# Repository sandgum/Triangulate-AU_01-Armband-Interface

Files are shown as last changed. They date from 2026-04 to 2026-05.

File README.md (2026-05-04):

# Triangulate-AU_01-Armband-Interface

## Description

A sci-fi-style armband interface running Android 14 on a Rockchip RK3576 module in a custom carrier board. Features an 8-inch 2.8K curved AMOLED with touch capabilities, a 2.1-channel speaker system with a 20W subwoofer, a 1080p pop-up webcam, various sensors, a huge battery at approx. 80Wh and 65W USB-PD charging. Perfect for use in the field with its bright display and long battery life.

## Enclosure

### Features
* 185mm long, with a radius of 56mm in the display section
* Four battery compartments housing 16x 1200mAh batteries with integrated cable channels
* Upwards-facing speaker channels for mid-high frequency drivers
* Integrated sealed subwoofer chamber
* Slim 38mm wide compute board in a hinged section
* Contoured inner profile (in contact with arm)
* Pop-up laptop webcam

### Images
au01 image 1
au01 image 3
au01 image 2

## Electronics

### Features
* PCIe x1 slot for NVMe SSD
* HDMI 2.1 port for display
* Two USB-C ports
* Port 1: USB-2.0, USB-PD-3.1 sink (Max. 20V) (for battery charging)
* Port 2: USB-3.0 SuperSpeed, USB-2.0, 5V 3A BC1.2 source (for peripherals)
* Approx. 60W battery charging via BQ25798
* Audio digital signal processing via ADAU1701
* 20W PAM8320 amplifier (for subwoofer)
* 2x 2W PAM8302 amplifiers (for L/R channels)

### PCB Schematics

Screenshot 2026-04-28 at 11 33 23 am

*Main RK3576 Module, HDMI, and PCIe*

Screenshot 2026-04-28 at 11 33 39 am

*USB-C Ports*

Screenshot 2026-04-28 at 11 33 50 am

*Battery Charger Circuit*

Screenshot 2026-05-04 at 12 30 20 pm

*Audio System Circuit*

### PCB Layout (Coming Soon!)

### Bill Of Materials (Coming Soon!)

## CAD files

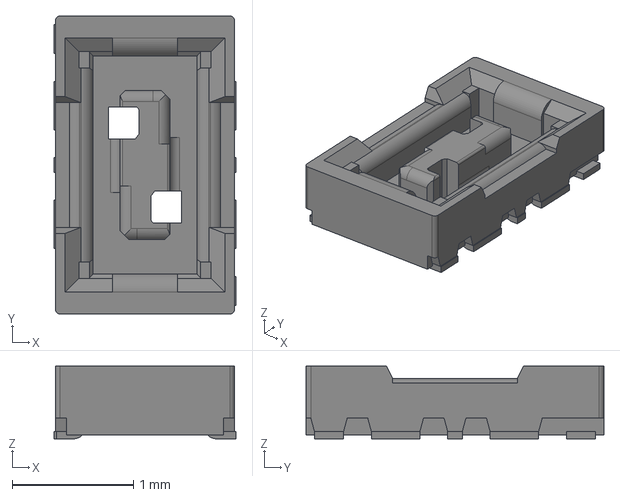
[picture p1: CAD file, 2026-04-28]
PCB/Additional Components/BM29B0.6-2DS_2-0.35V_51_/BM29B0.6-2DS_2-0.35V_51_.step
1.50 x 2.46 x 0.6 mm

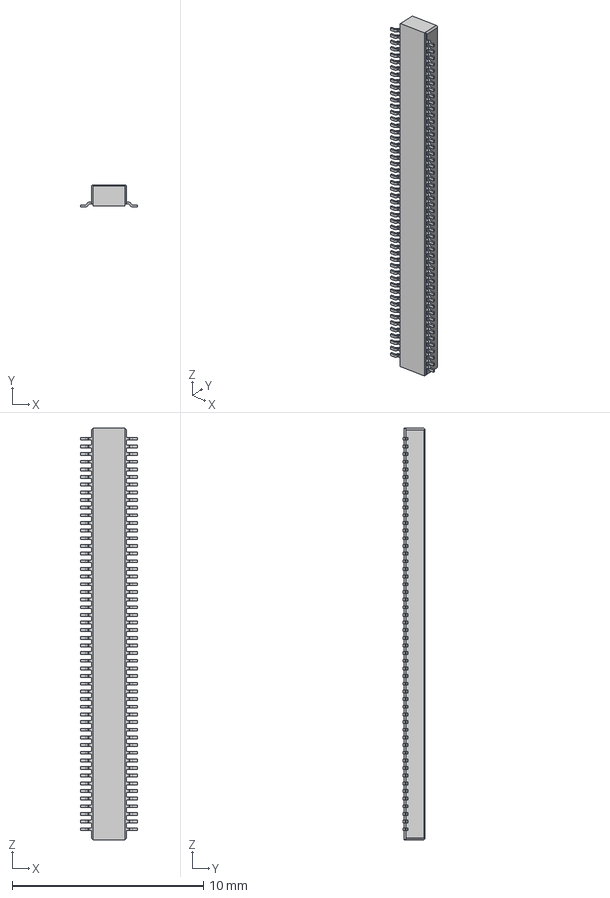
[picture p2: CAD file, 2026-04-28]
PCB/Additional Components/DF40C-100DP 0.4V Model/DF40C-100DP-0.4V_51_.step
2.97 x 1.14 x 21.5 mm

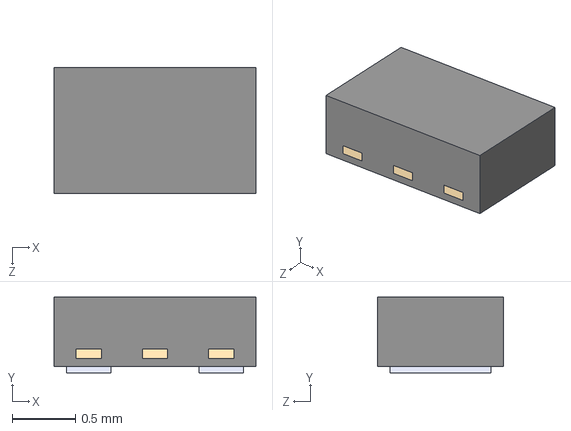
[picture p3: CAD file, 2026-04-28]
PCB/Additional Components/ESDA25P35 3D Model/ESDA25P35-1U1M.step
1.60 x 0.6 x 1.00 mm

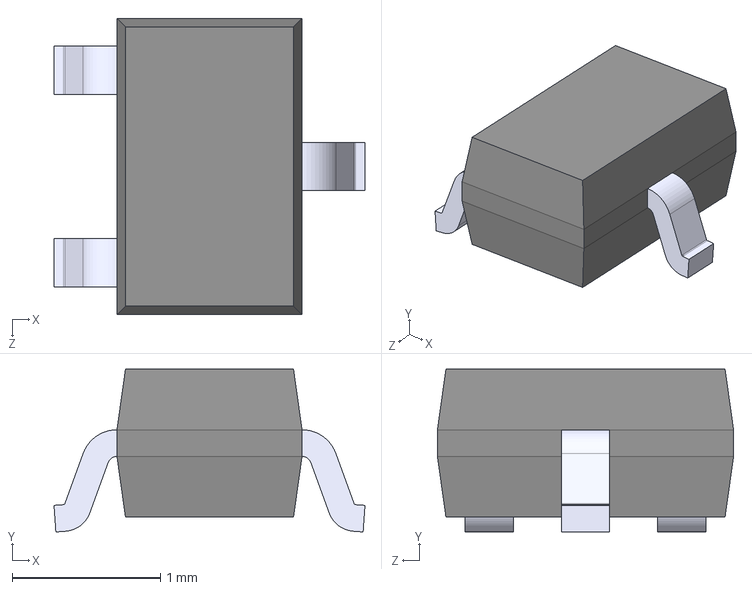
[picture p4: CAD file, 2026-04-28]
PCB/Additional Components/ESDA25W Model by STMicroelectronics/ESDA25W.step
2.10 x 1.10 x 2.00 mm

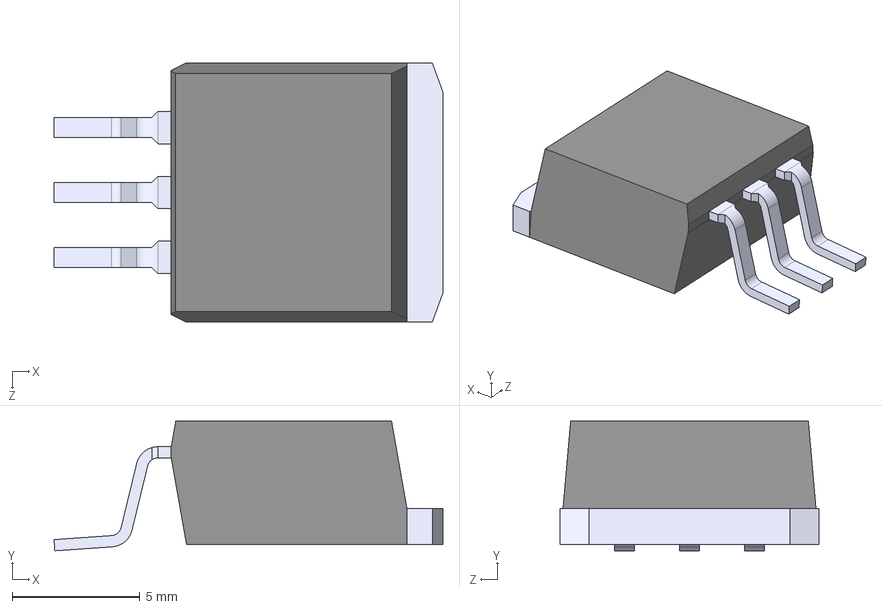
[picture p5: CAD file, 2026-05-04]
PCB/Additional Components/LM1085IS-12 Model/LM1085IS-12.step
15.2 x 5.08 x 10.2 mm

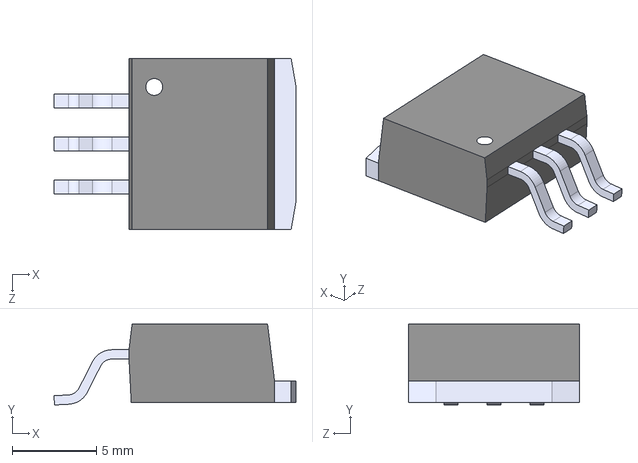
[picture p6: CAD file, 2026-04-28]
PCB/Additional Components/LM1085ISX-5.0_NOPB/LM1085ISX-5.0_NOPB.step
14.4 x 4.80 x 10.2 mm

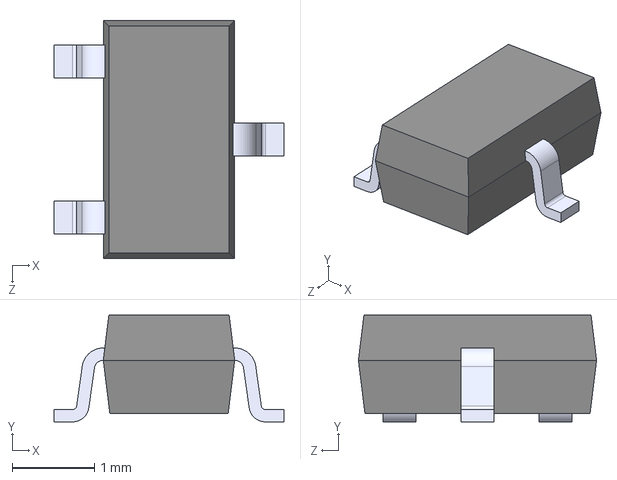
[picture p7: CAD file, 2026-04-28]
PCB/Additional Components/PMIC-LDO-XC6206P332MR-G_SOT23_/PMIC-LDO-XC6206P332MR-G_SOT23_.step
2.80 x 1.30 x 2.90 mm

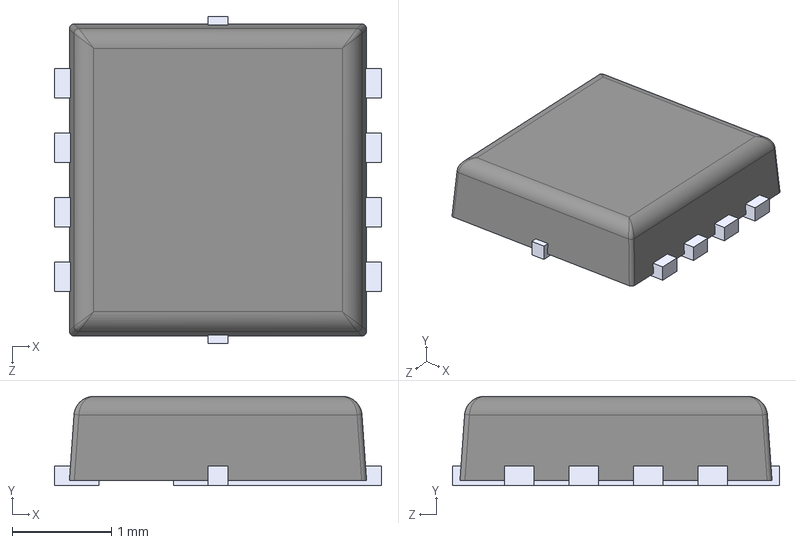
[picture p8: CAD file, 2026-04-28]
PCB/Additional Components/STL6P3LLH6 Model/STL6P3LLH6.step
3.30 x 0.9 x 3.30 mm

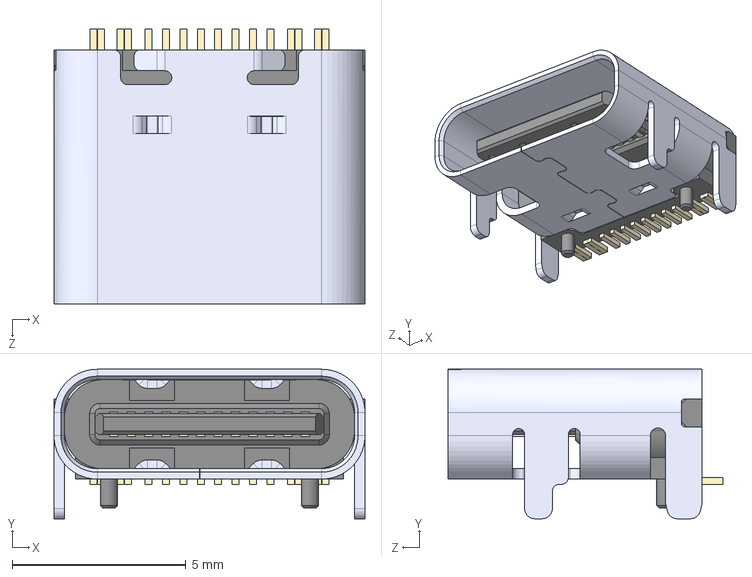
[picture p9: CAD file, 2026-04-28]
PCB/Additional Components/Type C 31 M 12 3D Model STEP 56544.STEP
8.94 x 4.30 x 7.90 mm

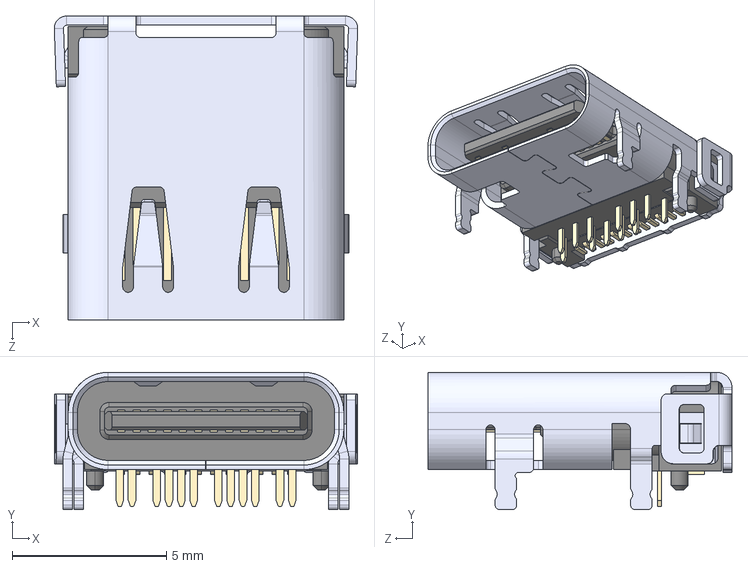
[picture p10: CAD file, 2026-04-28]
PCB/Additional Components/TYPE-C-31-M-04/TYPE-C-31-M-04.step
9.85 x 4.46 x 9.87 mm

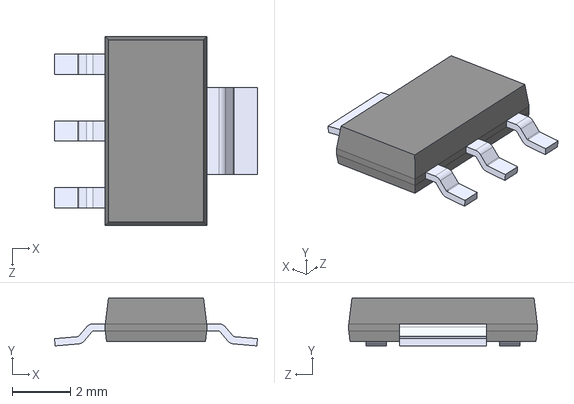
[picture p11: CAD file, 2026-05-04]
PCB/Additional Components/ZX5T953GTA Model/ZX5T953GTA.step
7.00 x 1.65 x 6.50 mm

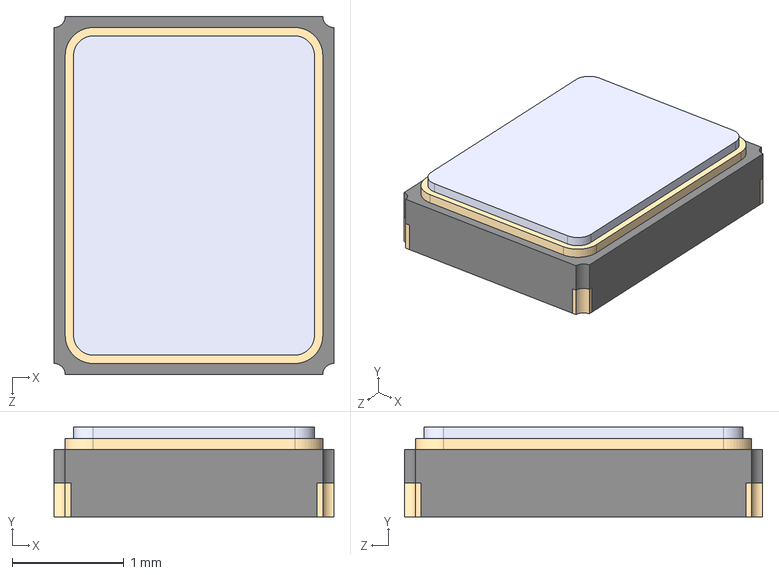
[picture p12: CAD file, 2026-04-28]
PCB/Additional Components/X322516MLB4SI/X322516MLB4SI.step
2.50 x 0.8 x 3.20 mm

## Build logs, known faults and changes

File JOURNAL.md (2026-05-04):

<!--
  This journal is auto generated by Stasis.
-->

# 5/4/2026 2 AM - Created Battery, Audio System Schematics

_Time spent: 5.75h_

After implementing the all-important USB-C ports, it was time to focus my attention towards the lesser, but still hugely important parts of the AU_01. 

To start, I researched various different multi-cell li-ion battery chargers. Initially, I wanted to use a BQ25730 IC from TI for its very fast maximum charging speed, but found that its application schematic required four external MOSFETs, without any recommendation for what model or parameters to even look for. I started researching suitable MOSFETs for this chip, but eventually I found that the schematic would take up too much space on the board, so I abandoned the idea of using that IC.

Screenshot 2026-05-04 at 12.06.23 pm

I then started reasearching again, finding a bunch of interesting options from TI again. Most notably, I found a much more integrated IC, the BQ25798, that incorporated all its MOSFETs into its package, saving me both valuable board space and also the headache and uncertainty of selecting my own MOSFETs for the charger. This did come with a tradeoff of only allowing around 60W of maximum charging power into my 4S pack. For an 80Wh system, that means it would take a minimum of around 1h 20m to charge the battery from 0 to 100%. It isn't as fast as I hoped to get it, but again, this thing has more battery capacity than my laptop and sips around the same or less power.

Screenshot 2026-05-04 at 12.07.08 pm

So there was my battery charger choice confimed, so I implemented the application schematic for it on a separate sheet, and that's when I ran into a problem. The BQ25798 requires some configuration and real-time management through I2C, which is easy enough to implement in my SoM, but that's where the problem lies. If I were to link the I2C up to my SoM, it would require the full system to be on just for the battery to charge, which would be a huge oversight that would affect usability. So for this application, I opted to use a tiny MAX32660 MCU (the same model used in the MS_01 studs!) because of its ridiculous power efficiency, tiny size and minimal external component count. After all, I only need this thing to write a couple of I2C registers and manage basic state.

Screenshot 2026-05-04 at 12.07.46 pm

Next, it was time to move on to designing the audio system circuitry. I want the AU_01 to have an integrated DSP and three amplifiers, one for each speaker driver. For the DSP, I used the easiest-to-program and most integrated option available, which is the ADAU1701 by Analog Devices. This DSP chip integrates DACs and ADCs, as well as internal logic circuitry and can be programmed easily using the SigmaStudio GUI. 

Screenshot 2026-05-04 at 12.09.55 pm

I chose the PAM8320 amplifier chip for the subwoofer, as it requires a minimal number of external components and is a well-known amplifier IC that can reliably deliver 20W for the Tectonic Elements driver. For the Dayton Audio stereo speaker, which only require 2W each, I used the PAM8302 amplifier chips for the same reasons as the larger amplifier, and I implemented the application schematics for all three chips. Conveniently, the PAM8302 ICs run perfectly on 5V, and the PAM8320 is fine with a 12V input. So the 5V supply for the smaller speakers can be shared with the SoM, and the 12V supply (after replacing the 1A regulator with a beefy 3A one) of the larger speaker can be shared with the OLED display, as its driver board takes a 12V input.

Screenshot 2026-05-04 at 12.10.25 pm

I then implemented the application schematic for the ADAU1701, and wired it so that it takes an I2S input and outputs three different analog signals, one for each
amplifier. 

Screenshot 2026-05-04 at 12.10.59 pm

During this, I ran into a problem, where the ADAU1701 specified using a 12.288MHz oscillator to generate a clock signal on its MCLK pin. This pin is also used by I2S, where the SoM provides its own MCLK for the chip to function at. Since MCLK can be driven at multiple clock frequencies (based on the sampling rate of the audio being played), I thought that foregoing the external oscillator and using the SoM's clock was a good choice. I also chose to do this because any mismatch in the MCLK between the chip's oscillator and the SoM's clock would result in the signal from the SoM (which depends on ITS clock) being jumbled up.

However, I realised that the ADAU1701 would require an instant clock signal upon power-on, and the SoM would definitely have some delay in turning on its MCLK. Also, since I'm using Android, it automatically limits its sampling rate to 48kHz, which results in a perfect 12.288MHz clock everytime. Therefore, I kept the external oscillator and left the SoM's MCLK signal unconnected. 

Now, the schematic for the entire AU_01 was pretty much done, and the only thing I needed to do was to add some sensors and supporting circuitry for a USB webcam.








# 4/28/2026 1 AM - Created USB-C Schematics

_Time spent: 5h_

Sooooo, I had to start actually creating the schematic diagrams for the various functions I want the AU_01 to support, and the most important (and probebly the hardest) one that I want to tackle are the USB-C ports that make up the primary method of interfacing with the device, and also the primary charging method.

I decided that I will include two USB-C ports on the device: One for USB-PD charging and USB2.0 data transmission for basic data transfer. For this, I used the STUSB4531 from ST, as it is a modern PD controller capable of running completely autonomously and is powered by the VBUS, so it can even charge completely dead batteries. Furthermore, the PD controller integrates a gate driver for a MOSFET for switching VBUS on and off, while also being able to negotiate contracts of more than 100W.

Screenshot 2026-04-28 at 11.13.08 am

The chip, however, only supports being a USB-PD sink, so it can only negotiate contracts where it takes power from an external source. This is why this port isn't good for unpowered peripherals (like keyboard/mouse dongles), as they simply won't receive any power. Additionally, the STUSB4531 hogs the CC pins on the USB-C port for itself, and it doesn't support USB-3.0 muxing across the port, so it will also be limited to USB-2.0 speeds. Considering the newest iPhones have that speed across their only USB-C port (yikes), I think the AU_01 having a full-speed USB-3.0 port in addition to the charging port is perfectly fine.

Screenshot 2026-04-28 at 11.16.03 am

Following the application schematic for the STUSB4531, and ddding the same high-speed low-capacitance ESD protector chips as I used in the HDMI port to the USB-2.0 data lines, the electrical design for the charging USB-C port was done. It can negotiate PD contracts up to 100W at 20V, which is perfect to charge the AU_01's battery in a reasonable time. Of course, there is a little bit of programming that needs to be done to the PD controller IC, but that only involves changing a few values in its NVM using an STM32 Nucleo board. That's why I've added a pin header for the chip's programming as well.

Next up was the design of the full-speed USB-3.0 port that also needs to provide power as a source to any peripherals or small dongles. This needed a set of different chips, which includes the FUSB302 Type-C controller and the TPS2547 power controller. The FUSB302 handles the CC pins and determines the USB-C plug's orientation. This then sends a signal to the I-CORE3576Q38 via I2C to let it know which orientation the port is in, which then results in the system module multiplexing its USB-3.0 signal to connect to the device.

In normal USB-3.0 outputs from a module, the signal multiplexing would be handled externally on the carrier board, but curiously the module I'm using has a multiplexer already inside. I used the FUSB302 to make sure that Linux recognises the device and lets the USB signal be routed to the correct pins.

To make sure any peripherals have adequate power supplied by the AU_01, I used the TPS2547 from Texas Instruments, which monitors the VBUS and negotiates power contracts up to 15W not using the CC pins, but the USB-2.0 data lines in an older protocol called BC1.2.

Screenshot 2026-04-28 at 11.17.16 am

Screenshot 2026-04-28 at 11.17.47 am

Connecting everything up to the system on module, I finally finished the implementation of USB-C on the AU_01. Next, I have to implement battery charging and other components like PCIe and MIPI-CSI for a camera.






# 4/10/2026 4 PM - Started PCB Design

_Time spent: 3.25h_

I finally started the main compute board design for the AU_01. Putting the main compute module on the schematic, I started working on the most important component of the board, which is the HDMI connector.

After finding a suitable connector that is cheap and in stock on LCSC, I routed the HDMI signals from the module to the connector. To add some ESD protection (because the RK3576 module is the most expensive part of the project), I placed a couple of ultra-low-capacitance ESD arrays designed for fast HDMI TMDS signals in the path of the lines. I placed another smaller ESD array for the I2C and Hot Plug Detect signals that are nowhere near as fast as the main TMDS signals, so the capacitance could be higher. Finally, I placed a high-power ESD diode for the 5V HDMI power rail, as well as a couple of decoupling capacitors for power stability.

Screenshot 2026-04-10 at 9.29.54 pm

The next part of the PCB I need to figure out is the whole charging circuit that uses USB PD through a Type-C port. This will require a PD controller IC, which range a lot in complexity and external component count. A cheap and easy option is to use the IP2366 IC, which integrates PD negotiation and battery charging all in one chip, but has sketchy documentation and is only available on AliExpress and AliBaba. Instead of this, I decided to go with a separate PD controller and charger combo from well-known brands.

I don't want to program any firmware for the controller (because that requires expensive programmers and introduces more points where my stupidity can cause failure), so the STUSB4531 by ST is a very good choice for my application. I then decided to pair that PD controller with a BQ25730 charging IC by TI, which can push up to 16.2A into my 4S pack.

Screenshot 2026-04-10 at 9.30.40 pm
Screenshot 2026-04-10 at 9.31.20 pm

To balance 4 series cells, it would have been too complicated (and dangerous) to prototype my own balancing circuit, so I decided to use an off-the-shelf module from AliExpress.

Next, I have to wire up these two ICs and complete the whole PD circuit!





# 4/9/2026 4 PM - Created I-CORE3576Q38 Footprint and Symbol

_Time spent: 2.5h_

This genuinely took a crazy amount of time. 

I went to start designing the PCB schematic, only to find that I couldn't find ANY footprint or symbol for the Firefly I-CORE3576Q38 anywhere. I had to message the manufacturer on WhatsApp to even get a 3D model and mechanical drawing, and I traced the connector model to the DF40HC(3.0)-100DS-0.4V(51) and DF40C-100DP-0.4V(51) by Hirose.

Screenshot 2026-04-09 at 10.10.22 pm

After getting the footprint and symbols for those two connectors, I merged them together to make a symbol, where I had to manually copy and paste all the pin names and pin numbers from the module's datasheet. This was by far the most time consuming part, as there are 200 pins to name on the module.

Screenshot 2026-04-09 at 10.08.49 pm

The PCB footprint was equally tedious, as I had to re-number every pin on one of the connectors to make it match with the symbol. I also used the 3D model of the module for reference to precisely place each connector so that it would line up with the expected boundaries of the module, and more importantly, line up relative to each other. Taking care to note which side of the module pin 1 on either connector was facing, I finally finished the footprint for this module (in true April fasion, complete with a couple of silkscreen Easter eggs!).

Screenshot 2026-04-09 at 10.09.39 pm





# 4/7/2026 4 PM - Modelled compute unit section, enclosure done!

_Time spent: 2.5h_

I had finally finished almost all of the enclosure for the AU_01, and the only thing left to model was the section that houses the main compute board. This board will be a carrier board for the RK3576 module, have HDMI and USB for connection to the display, have a Li-ion battery charging circuit with USB PD, have three discrete audio amplifier circuits, a 2.1-channel DSP for equalising them all, and finally some support for a MIPI or USB webcam. All of these features on a single-sided board would require it to be quite large, so I decided to model a compute board that takes up the full length of the AU_01.

Screenshot 2026-04-07 at 10.04.49 pm
Screenshot 2026-04-07 at 10.05.39 pm

The last section of the AU_01 will need to pivot in order to allow for an arm to slide in, so that required a cable cutout for the display driver board cables to go through the outside of the unit (that saves space, and looks nice as well!). Looking at the rest of the space, a reasonably thick PCB with the 38x38mm compute module can easily fit, and I could also just sqeeze four additional batteries into that space to create a 4S4P pack. This would bring up the total capacity to a whopping 71Wh, which gets quite close to the capacity in the much more power-hungry MacBook Pro 14 inch.

Screenshot 2026-04-07 at 10.06.18 pm
Screenshot 2026-04-07 at 10.06.53 pm

The design of the 3D model is effectively complete, and now I can start with the design of the compute PCB!






# 4/6/2026 1 PM - Display/Battery enclosure, Speaker System!

_Time spent: 4h_

With the basic shape of the rest of the display enclosure (the part that houses the bulky display driver board) figured out, I extruded that shape and joined it with a thin 1mm thick section covering the display. This display cover is meant to protect the edges of the OLED, which are usually very sensitive especially on flexible displays.

There was a cut made in the extruded display driver section for the display driver itself, with 10mm of space left on either side of it as I am unsure of the horizontal position of the driver board in relation to the display (that wasn't a dimension on the mechanical drawing!).

Screenshot 2026-04-06 at 6.59.28 pm

This was when I realised that I still had not figured out a sound system solution for this project, and since this is going to be a fully-featured general-purpose device, the ability to produce sound is a must. I saw that there was a lot of wasted space in the display driver board enclosure, which was too weirdly shaped to fit a battery or another PCB, so I decided to use this as volume for a tiny speaker box!

Since the AU_01 has so much space, I might as well use some of it to put a sound system that can rival most LAPTOPS, let alone phones. So I started finding the perfect components for it. Using my past speaker design experience (I have designed a couple of Bluetooth speakers before, but not on Hack Club), I wanted to find a small yet capable driver that can act as a bass-midwoofer for a 2.1-channel system that ws going to go in the AU_01.

I found an amazing 1-1/8 inch driver from Tectonic Elements that can reach down well below 100Hz in its frequency response given enough power (up to 20n watts!) and clever equalisation. This will complement a pair of extremely loud mid-to-high frequency speakers from Dayton Audio that will make the AU_01's sound system on par with some standalone Bluetooth speakers (definitely in amplitude, maybe in frequency response).

Screenshot 2026-04-06 at 7.00.05 pm
Screenshot 2026-04-06 at 7.00.33 pm

Hollowing out the largest unused void near the display driver, I found that the Tectonic Elements TEBM28C10-4/A fits pretty much perfectly in that space, and the small amount of space it has should be fine as the driver delivers its lowest sealed frequency in a space of just 38mL of volume.

Screenshot 2026-04-06 at 6.58.49 pm

Placing the two smaller mid-tweeters was a bit more of a challenge, as these should ideally be facing directly towards the user, but the only place on the enclosure that allows for that is taken up by the huge display. Placing the drivers tangent to the curvature underneath the display would make them point pretty much directly downwards, but I eventually came up with a solution.

Pretty much all phone speakers have much larger drivers than can fit in the thickness of the phone, so all manufacturers place the driver 90° away from the speaker cutout, and have a channel direct sound from the driver to the speaker cutouts. This is what I did, with an angled speaker cutout leading to the drivers further in the chassis. This will hopefully direct sound towards the user, preserving higher freqencies and making them heard for better sound quality. It also comes with the benefot of protecting the paper cone drivers, and also hiding them because they are not very aesthetically pleasing.

Screenshot 2026-04-06 at 7.01.21 pm
Screenshot 2026-04-06 at 7.01.46 pm
Screenshot 2026-04-06 at 7.02.16 pm
Screenshot 2026-04-06 at 7.02.41 pm

To add some final finishing touches, I added a fillet around everything and added a nice circular pattern on the blank sides of the speaker enclosure to make a visually interesting pattern.

Screenshot 2026-04-06 at 7.03.10 pm











# 4/5/2026 9 AM - Designed battery/display enclosure

_Time spent: 3.5h_

Now that the main components of the AU_01 had been decided, I started importing accurate 3D models of each component into Shapr3D to build an enclosure around them.

Firstly, since this device is meant to clasp around the user's arm, so I measured the circumference of my left forearm at multiple points and used splines to model it roughly. Since my arm is not a perfect cylinder (nobody's arm is), I then modeled a plastic base section that wraps around the arms curvature and provides a flat platform for all of the electronics and the rest of the enclosure to sit on.

Screenshot 2026-04-05 at 2.44.33 pm

Screenshot 2026-04-05 at 2.45.26 pm

I then began working on the section of the enclosure which houses the display and the main batteries of the unit. As I wanted the AU_01 to have a sleek design, the bend radius of the display was quite small at just 55mm. Using some simple maths, I managed to accurately model the display bent at this radius with its real dimensions taken from its mechanical drawing. With this radius, the display managed to wrap around at an angle of more than 130°! This really made the whole device look that much more futuristic.

Screenshot 2026-04-05 at 2.46.22 pm

Between the display and the user's arm, I found that there was enough space to store all of my batteries, which is an especially good use of space since most circuit boards (including the bulky display driver board) would not be able to fit in this tightly-curved space. I managed to squeeze in 12 of these long and skinny 1200mAh cells in this space, which I'll wire up to make a 3S4P pack (3 cells in series, 4 in parallel, 3*4=12) with a total estimated capacity of 53.28 Wh! That is very close to the battery capacity in Apple's MacBook Air 13 inch laptop! The RK3576 and display are very power-hungry, so this capacity is a must. I might even add more batteries later!

Screenshot 2026-04-05 at 2.47.00 pm

The batteries had enclosures made for them which allow them to simply slide in, and for their wires to enter a cable channel in the middle where all the wires can be joined to form the pack. Lastly in the battery section, I added some voids that serve to both break up the boring front of the device, but also remove extra material, making the whole device slightly lighter.

Screenshot 2026-04-05 at 2.47.36 pm
Screenshot 2026-04-05 at 2.48.15 pm
Screenshot 2026-04-05 at 2.48.49 pm

I modeled the display's driver board and flex cable afterwards, and that's when I found a pretty huge problem: The driver board is 84mm long, and it can only be placed in a certain orientation relative to the display. This board would stick out from the rest of the device due to its curvature, and making the whole device thicker to accomodate it would make it way too bulky. I could ask the supplier to make a custom driver board that is smaller, but that incurs a $700 USD cost (Yikes!).

Screenshot 2026-04-05 at 2.49.48 pm

I eventually found a solution to this problem by leveraging the power of tangent circles. Initially, I wanted the whole unit to be one cylinder, but when I added a couple of smaller tangent circles to the main one, and a big tangent circle to bridge the transition, suddenly I was left with a shape that is both aesthetically pleasing (not bulky) and had enough space in the bottom for the driver board.

Screenshot 2026-04-05 at 2.51.01 pm

Next, I will model the actual enclosure for the driver board and the cover for the display to protect its edges.











# 4/4/2026 9 AM - Basic Idea, Component Hunting!

_Time spent: 4.25h_

Sooooooo I kinda like sci-fi movies, I'll admit that. And in almost all of these movies, the main character is seen with some sort of armband computer that they use to communicate with others and to perform basic tasks. I've always been intrigued by the form factor of basically putting a phone on your arm, but questioned its viability as a separate device because, well, you *can* just strap a phone to your arm and have an armband computer.

That's until I realised the amazing things that can be designed onto a device meant for your arm, such as a huge battery, huge curved screen, and the ability to actually fit off-the-shelf processors that can rival those in modern phones (All the *real* phone processors are tiny, but completely inaccessible to a random teen like me) plus, let's face it, it's pretty awesome to have a sci-fi computer on your arm.

So, with the goal of maximizing the potential benefits of putting a beefy phone on an arm, I started searching for the integral components this whole project will be built around. Most importantly, I wanted to get the display locked in.

I started on AliExpress, searching for OLED and AMOLED displays with touch functionality, and found an abundance of listings with either sky-high prices, or a lack of crucial features like the ability to bend (Flat displays don't mix well with round arms) or just being like 5 inches diagonally, which is smaller than pretty much all phones.

Screenshot 2026-04-04 at 2.57.38 pm

Disappointed, I went to Alibaba, on which I found much better deals for the same stuff being sold on AliExpress. The minimum order quantities for most of these displays were also just 1, so there were pretty much no downsides. I messaged three different sellers asking for datasheets and quotes on samples, and I found the best features and value in a display from Shenzhen Startek Electronics, which sells an 8-inch 2.8K resolution flexible AMOLED with touch and a HDMI driver board for just $126 USD.

Screenshot 2026-04-04 at 2.58.36 pm

Screenshot 2026-04-04 at 3.00.15 pm

Another one of my requirements was the display having a HDMI driver board, as the MIPI DSI interfaces used by these displays requires dedicated (often custom) drivers to run on the application processor, as well as precise timing and accurate trace placement. I would much rather offload that work to an external MCU which just takes in HDMI from the application processor.

With the display more or less confimed, I then started searching for a system-on-module that is both powerful enough to run Android smoothly, but small and cheap enough to be in this project. The first choice  was to use a Raspberry Pi Compute Module 5, which is currently the industry standard with extensive community support and documentation, as well as a stable Android build. Plus, it has more than enough power to run Android easily. This, however, is WAY too expensive for this project, with 8GB RAM versions (The minimum I need for smooth Android) coming in at more than the cost of my display.

Screenshot 2026-04-04 at 3.01.13 pm

I then turned to Rockchip's line of processors, which have a huge variation in module designs for them. The flagship RK3588, again, costs way too much as well as consuming too much power, but the mid-range RK3576 is just the right balance of performance and efficiency with amazing display capabilities, eight cores, and less heat generated. Moreover, the RK3576 has more modules made for it, including one amazing little 38x38mm module with 8GB of RAM that costs around $40 AUD less than the equivalent Raspberry Pi 5. The ICORE-3576Q38 by Firefly is just the right fit for this project, as the main compute board is guaranteed to be space-restricted.

Screenshot 2026-04-04 at 3.01.46 pm

Now, how do I power this whole thing? Even through the RK3576 is efficient, it isn't even in the same league as phone processors. Also, my huge OLED screen is guaranteed to consume a lot of power, as well as my speaker system (stay tuned for that!). So I found pretty much the perfect batteries to incude, which are thin and narrow (90x30x3mm) so they can fit between the main display and the user's arm.

Screenshot 2026-04-04 at 3.06.24 pm    

Now that the main 3 components of the AU_01 have been selected, I can start modelling the enclosure of the unit itself!








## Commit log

2026-04-04 Update battery capacity in project description
2026-04-09 Created SoM Footprint and Symbol, Started Project
    [AU_01_MainPCB.kicad_pcb, AU_01_MainPCB.kicad_sch]
2026-04-28 Created USB-C Schematic
    [AU_01_AudioSystem.kicad_sch, AU_01_BatteryCircuit.kicad_sch, AU_01_MainPCB.kicad_sch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]
2026-04-28 Added CAD File
2026-05-04 Audio, Battery Schematic, added Journal
    [AU_01_AudioSystem.kicad_sch, AU_01_MainPCB.kicad_sch, LM1085IS-12.step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]
2026-05-04 Update README.md with audio circuit
